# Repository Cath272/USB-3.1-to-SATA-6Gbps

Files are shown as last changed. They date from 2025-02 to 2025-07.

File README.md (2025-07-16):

# USB-3.1-to-SATA-6Gbps
USB 3.2 gen 2 (SuperSpeed+ 10Gbps) to SATA 6Gbps

This Board is based on the VIA Labs VL716 

## VL716

- High performance, low power single chip USB 3.1 to SATA 6Gb/s bridge controller 
- USB Type-C connector support
###  Built-in Voltage Regulators

- 5.0V to 3.3V LDO

- 5.0V to 1.2V switching DC-DC

## Other Parts 

- USB C 24P Connector (THT inside pins)
- 25Mhz Crystal for Ic
- Sata 22P horizontal female SMD connector
- W25Q16BVSSIG 16Mbit SPI Flash  Memory
- 1.5uH/2.2uH Inductor
- Power/Busy LEDs

## PCB 
This board uses a 4 layer stackup with a  1.6mm thickness:

- POWER/SIGNAL

- GND
  
- GND
  
- POWER/SIGNAL

High Speed diferential lines need a refrence ground plane so internal planes are ground referance planes for the High speed USB lines

The Pcb was inspired by similar boards that use VL711/VL715 Ics. The capacitors are standard values that are use as decoupling capacitors.

### Schematic:
Schematic

## PCB Screenshots

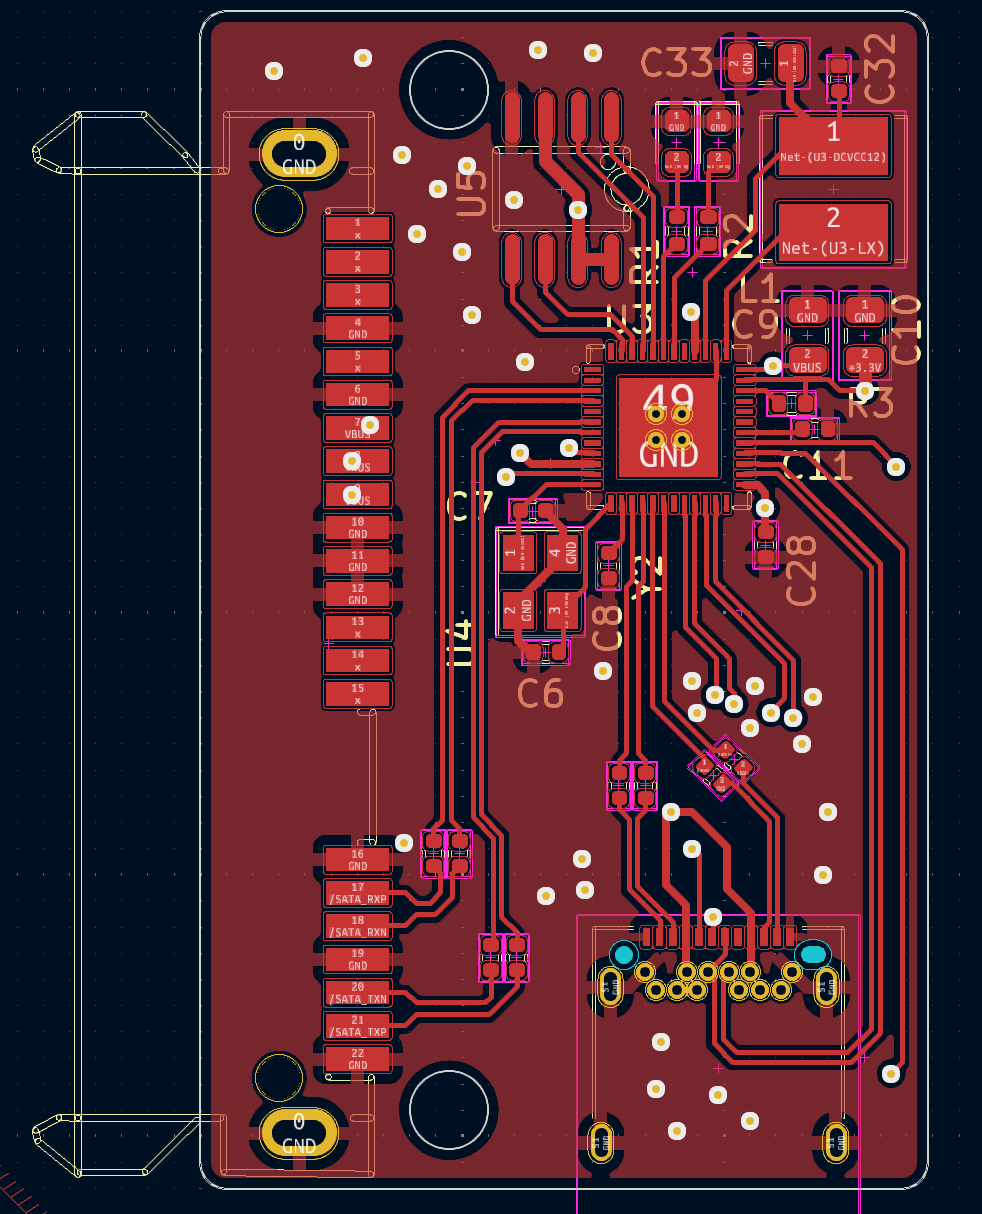
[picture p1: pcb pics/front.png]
usb3satafront

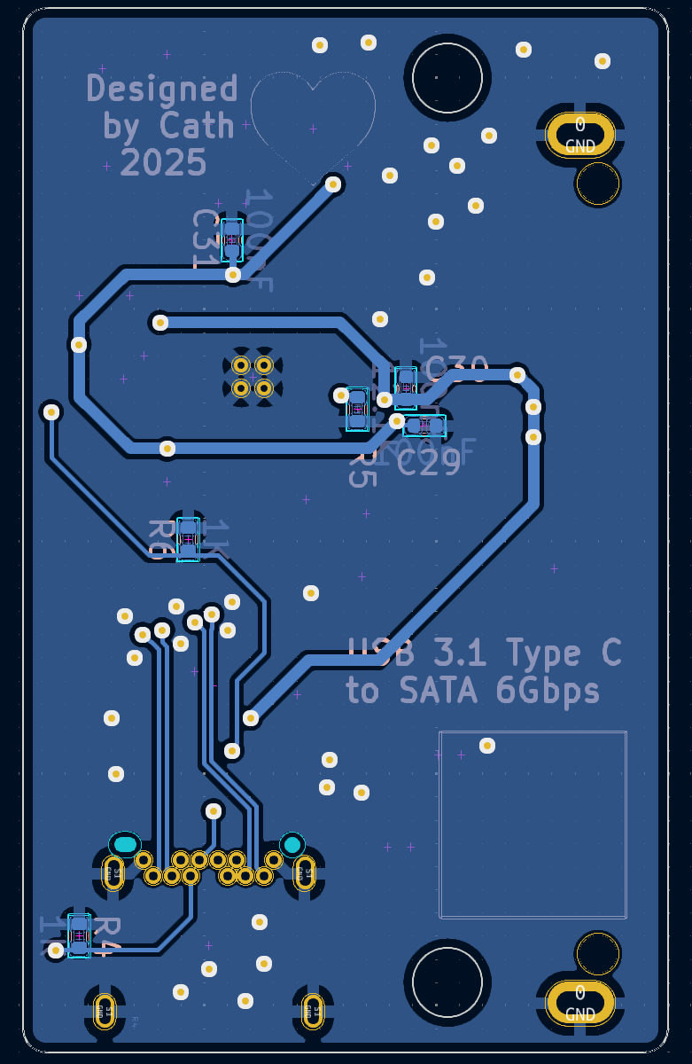
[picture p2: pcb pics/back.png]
usb3sataback

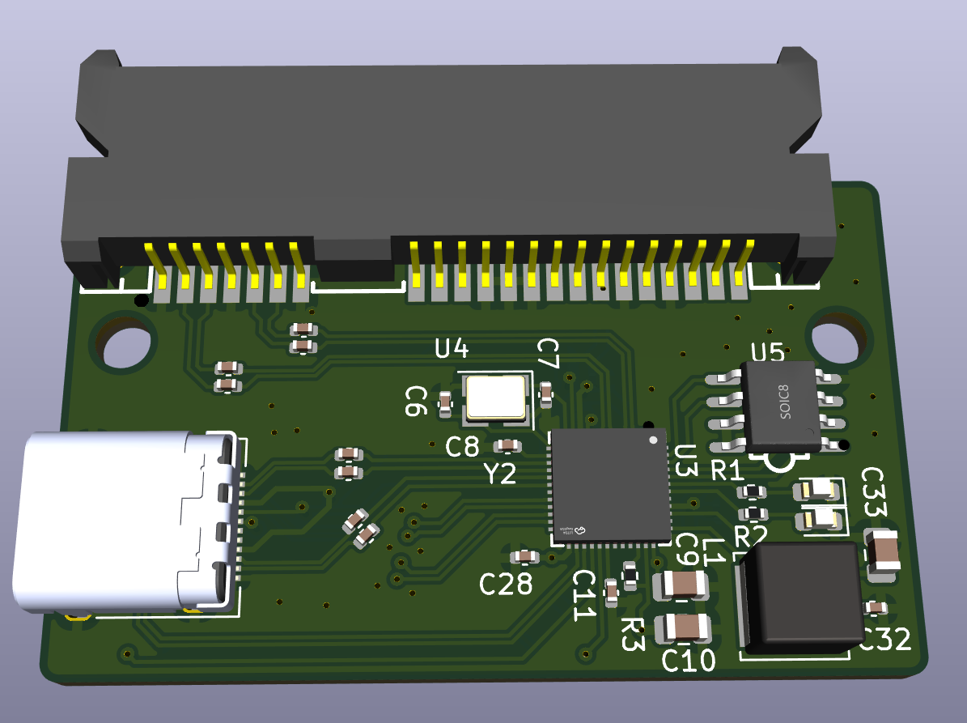
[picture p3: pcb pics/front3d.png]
usb3satafront3d

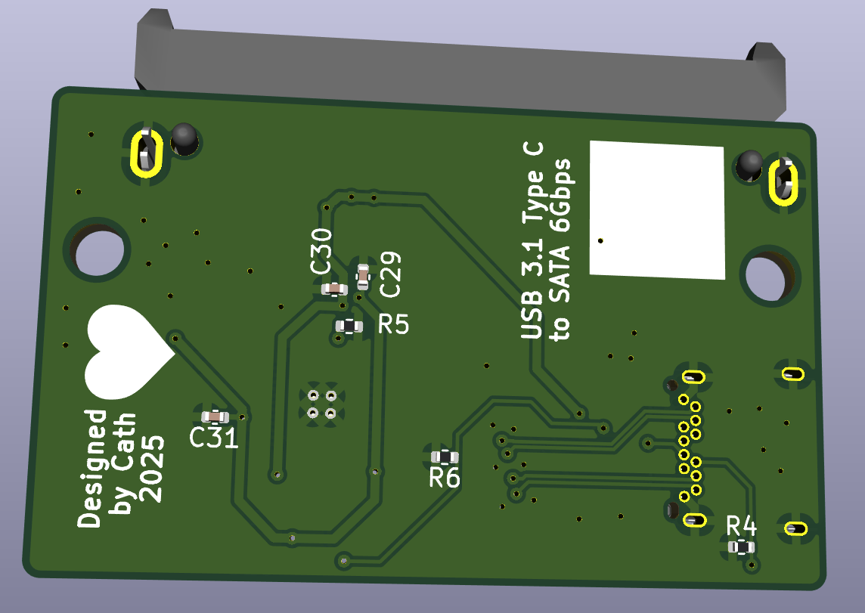
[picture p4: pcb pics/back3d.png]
usb3sataback3d


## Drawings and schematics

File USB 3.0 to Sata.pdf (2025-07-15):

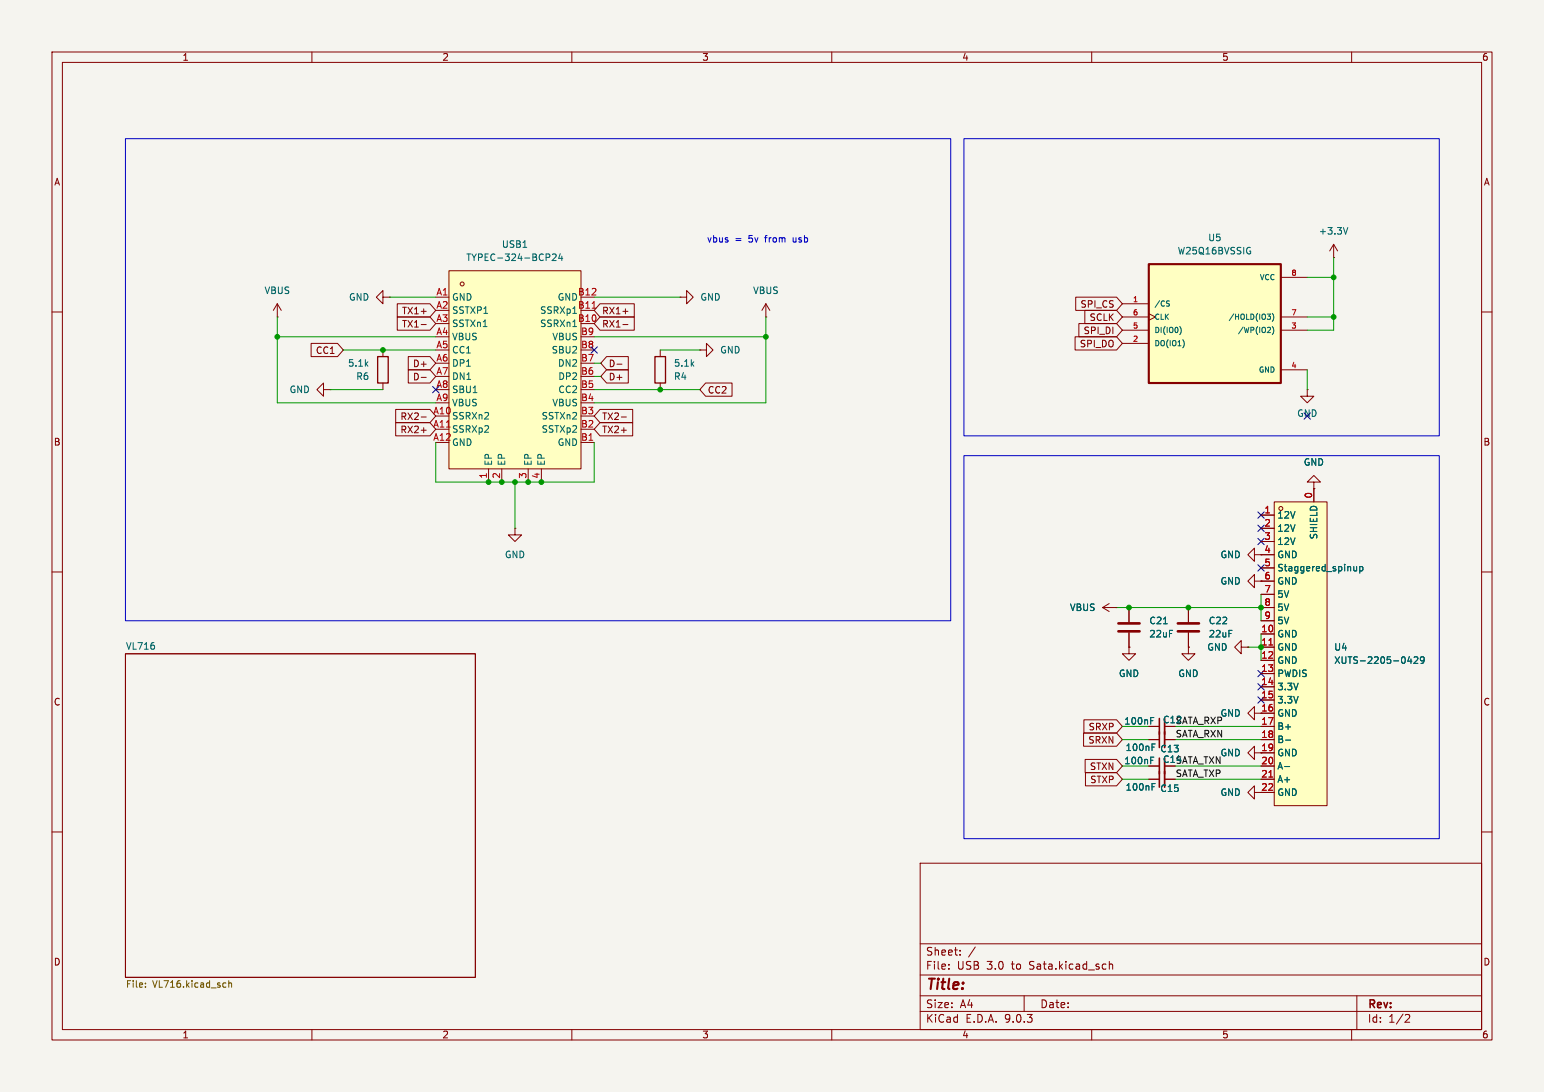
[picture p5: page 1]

4 GNDB12 SSRXp1 B11 SSRXn1 B10 VBUS B9 SBU2 B8 DN2 B7 DP2 B6 CC2 B5 VBUS B4 SSTXn2 B3 SSTXp2 B2 GND B1 USB1 TYPEC-324-BCP24

Id: 1/2 Title: File: USB 3.0 to Sata.kicad_sch Sheet: / VL716 File: VL716.kicad_sch

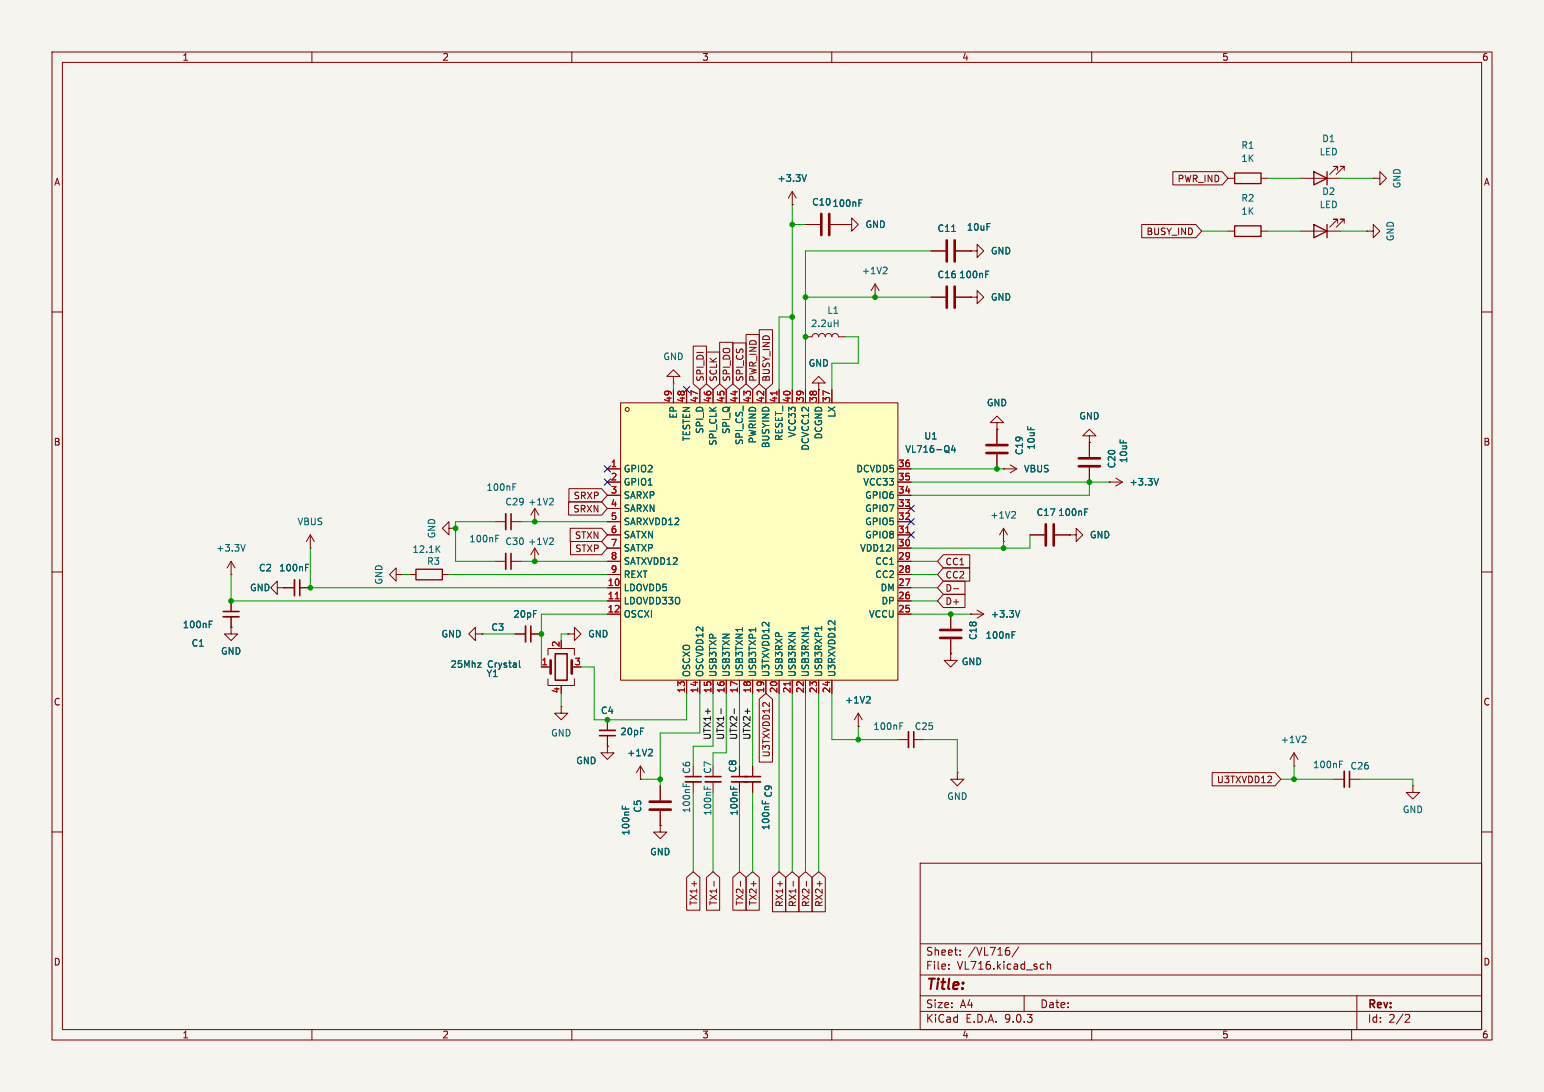
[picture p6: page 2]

Id: 2/2 Title: File: VL716.kicad_sch Sheet: /VL716/

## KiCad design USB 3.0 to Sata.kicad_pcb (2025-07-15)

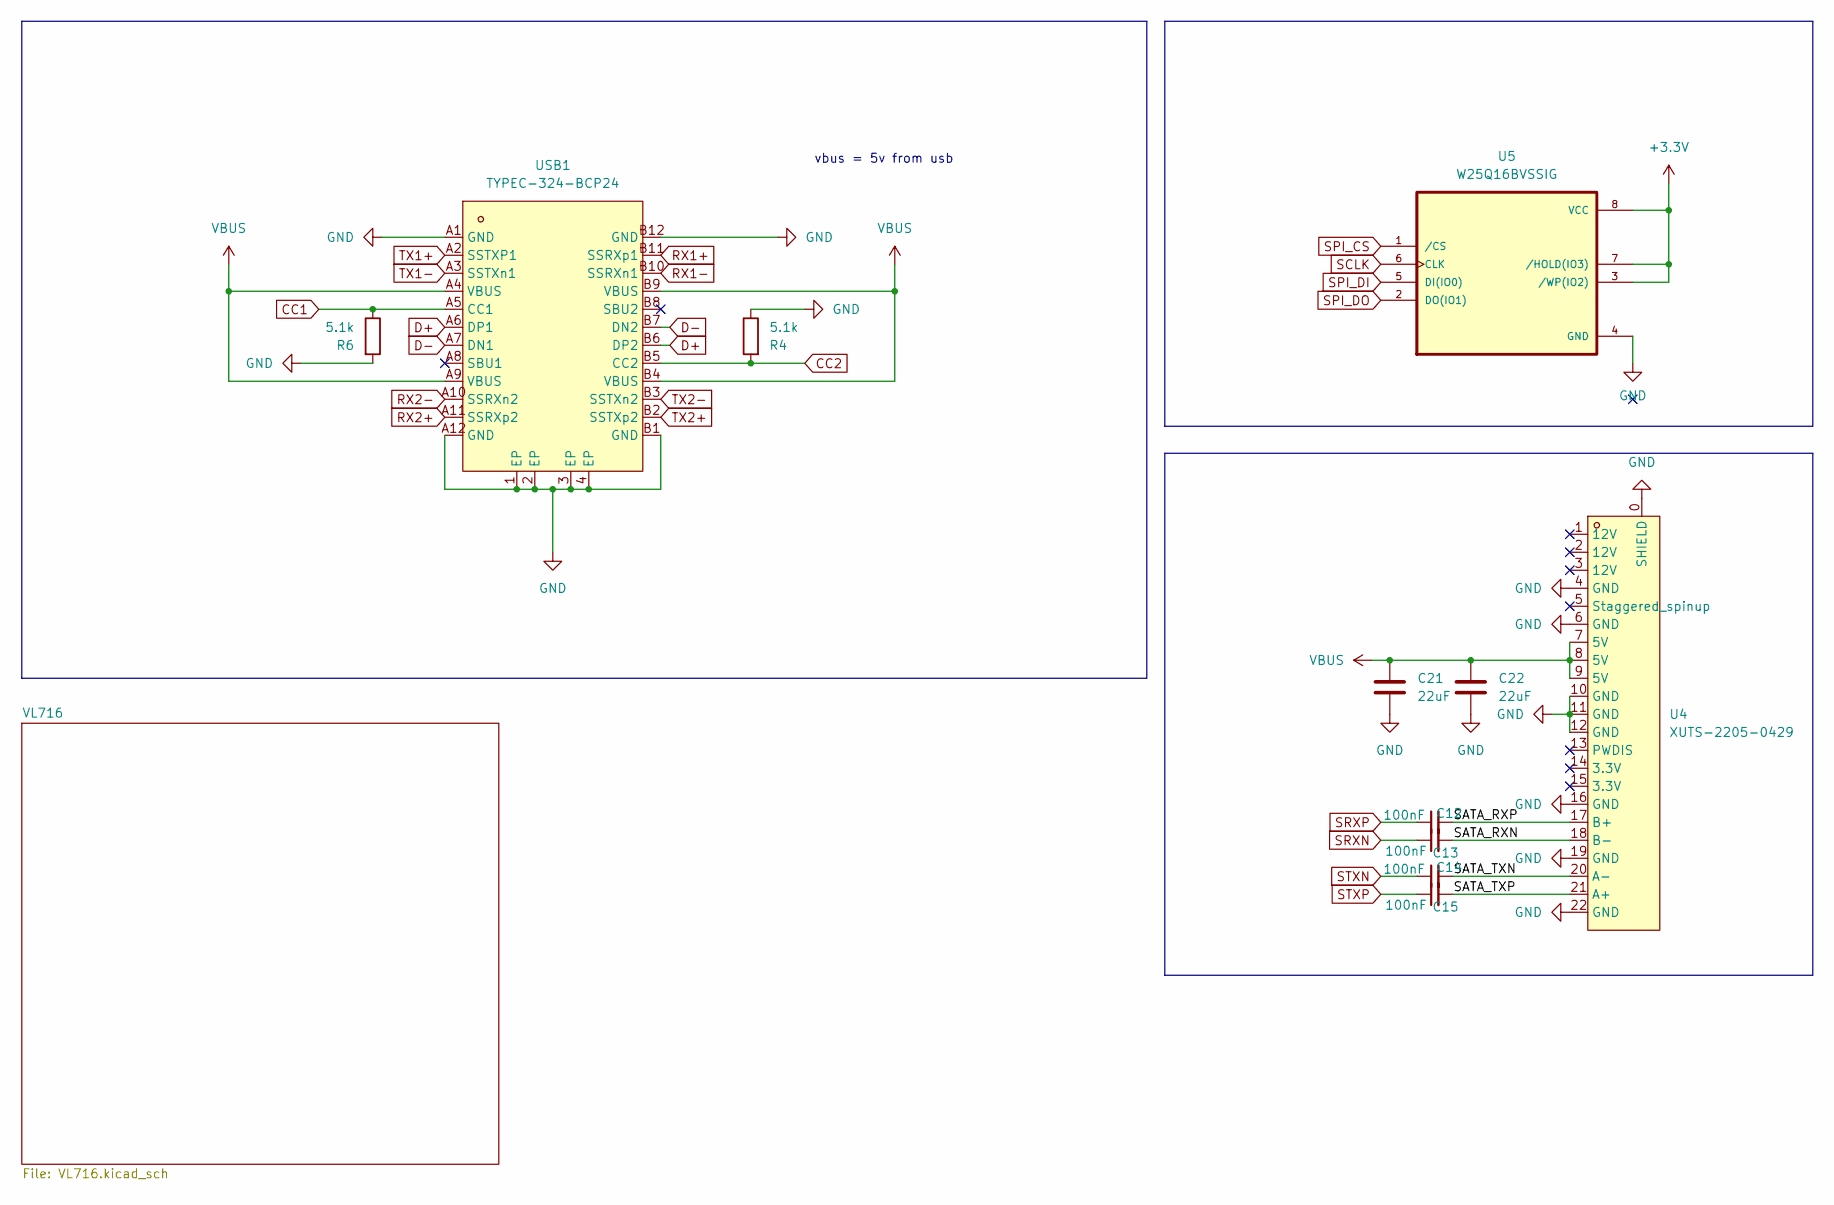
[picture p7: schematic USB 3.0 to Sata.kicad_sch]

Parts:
C12, C13, C14, C15: 100nF; C_0402_1005Metric
C21, C22: 22uF; C_0805_2012Metric
R4, R6: 5.1k; R_0402_1005Metric
U4: XUTS-2205-0429; CONN-SMD_UTS-2205-0429; LCSC Part C7527511
U5: W25Q16BVSSIG; SOIC-8_L5.3-W5.3-P1.27-LS8.0-BL; PARTREV F
USB1: TYPEC-324-BCP24; USB-C-SMD_TYPEC-324-BCP24; LCSC Part C2835314

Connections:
+3.3V: U5.3 (/WP(IO2)), U5.7 (/HOLD(IO3)), U5.8 (VCC); also elsewhere on the board
/SATA_RXN: C13.2, U4.18 (B-)
/SATA_RXP: C12.2, U4.17 (B+)
/SATA_TXN: C14.2, U4.20 (A-)
/SATA_TXP: C15.2, U4.21 (A+)
CC1: R6.1, USB1.A5 (CC1); also elsewhere on the board
CC2: R4.2, USB1.B5 (CC2); also elsewhere on the board
D+: USB1.A6 (DP1), USB1.B6 (DP2); also elsewhere on the board
D-: USB1.A7 (DN1), USB1.B7 (DN2); also elsewhere on the board
GND: C21.2, C22.2, R4.1, R6.2, U4.0 (SHIELD), U4.4 (GND), U4.6 (GND), U4.10 (GND), U4.11 (GND), U4.12 (GND), U4.16 (GND), U4.19 (GND), U4.22 (GND), U5.4 (GND), USB1.1 (EP), USB1.2 (EP), USB1.3 (EP), USB1.4 (EP), USB1.A1 (GND), USB1.A12 (GND), USB1.B1 (GND), USB1.B12 (GND); also elsewhere on the board
RX1+: USB1.B11 (SSRXp1); also elsewhere on the board
RX1-: USB1.B10 (SSRXn1); also elsewhere on the board
RX2+: USB1.A11 (SSRXp2); also elsewhere on the board
RX2-: USB1.A10 (SSRXn2); also elsewhere on the board
SCLK: U5.6 (CLK); also elsewhere on the board
SPI_CS: U5.1 (/CS); also elsewhere on the board
SPI_DI: U5.5 (DI(IO0)); also elsewhere on the board
SPI_DO: U5.2 (DO(IO1)); also elsewhere on the board
SRXN: C13.1; also elsewhere on the board
SRXP: C12.1; also elsewhere on the board
STXN: C14.1; also elsewhere on the board
STXP: C15.1; also elsewhere on the board
TX1+: USB1.A2 (SSTXP1); also elsewhere on the board
TX1-: USB1.A3 (SSTXn1); also elsewhere on the board
TX2+: USB1.B2 (SSTXp2); also elsewhere on the board
TX2-: USB1.B3 (SSTXn2); also elsewhere on the board
VBUS: C21.1, C22.1, U4.7 (5V), U4.8 (5V), U4.9 (5V), USB1.A4 (VBUS), USB1.A9 (VBUS), USB1.B4 (VBUS), USB1.B9 (VBUS); also elsewhere on the board

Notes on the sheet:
vbus = 5v from usb

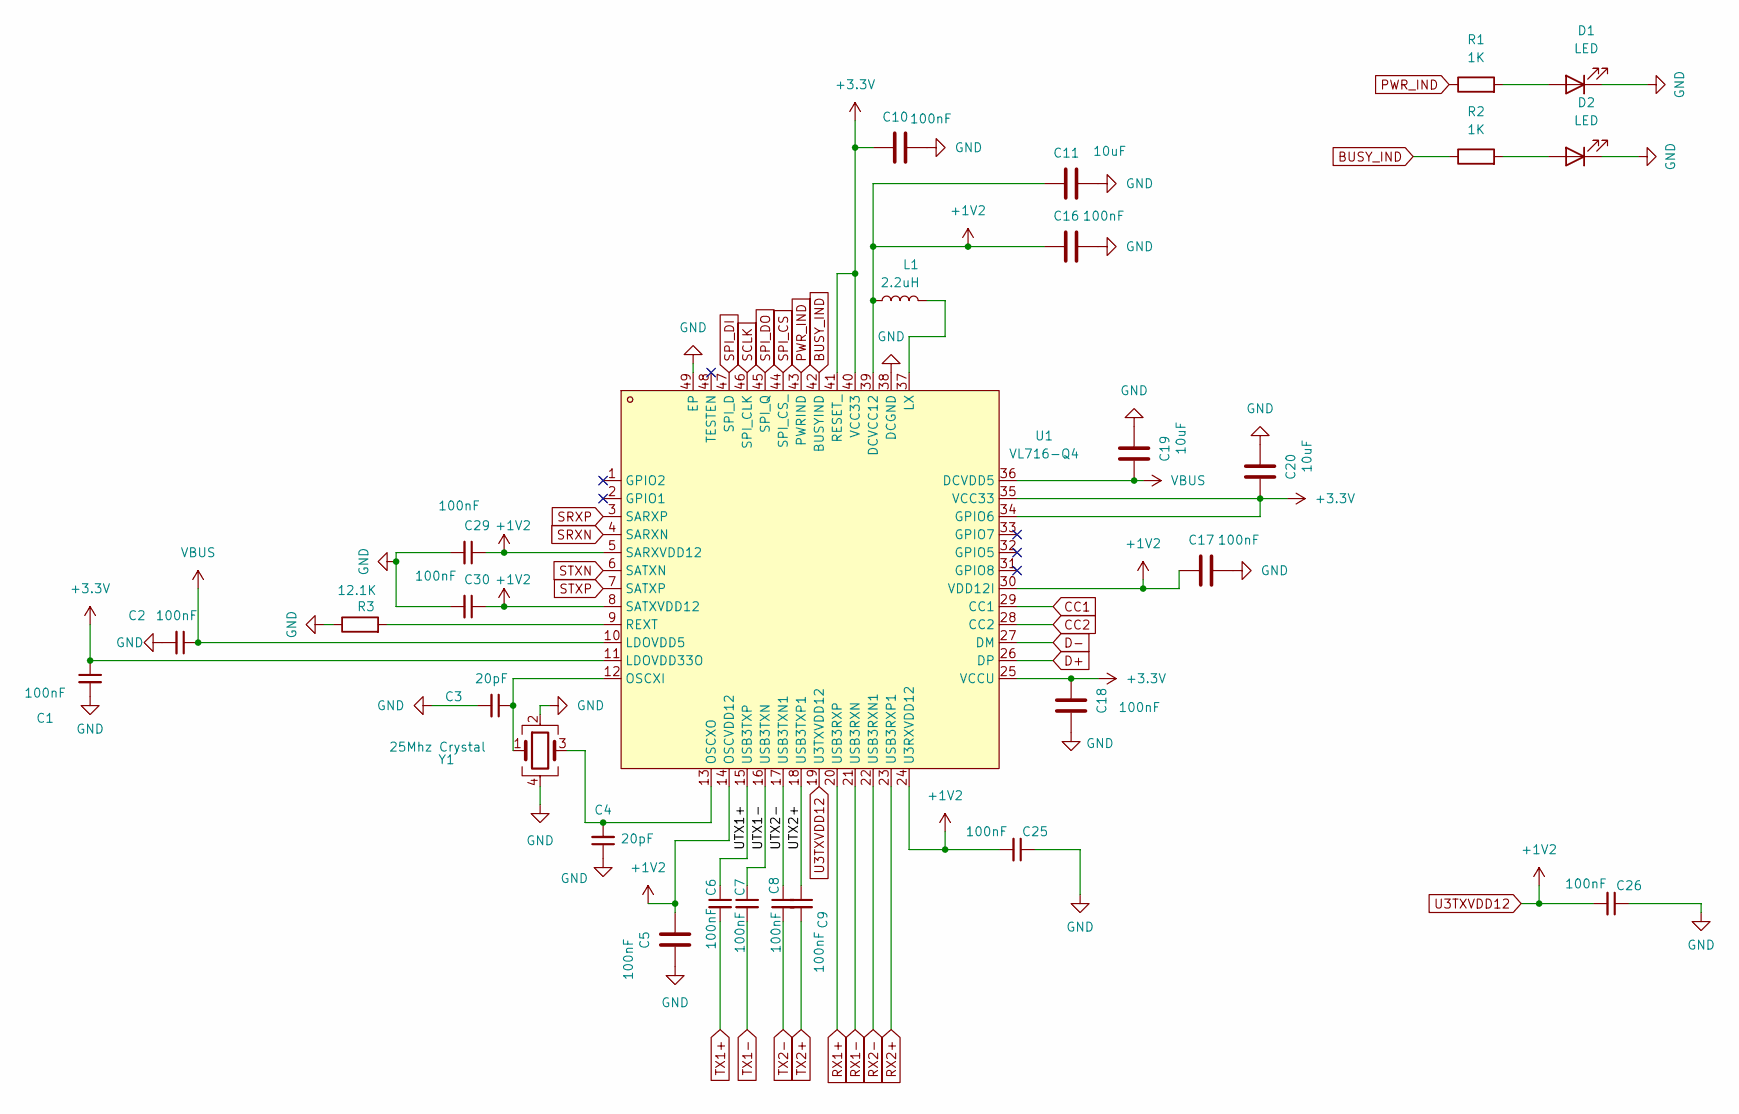
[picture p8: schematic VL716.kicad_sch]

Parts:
C1, C2, C5, C6, C7, C8, C9, C10, C16, C17, C18, C25, C26, C29, C30: 100nF; C_0402_1005Metric
C3, C4: 20pF; C_0402_1005Metric
C11, C19, C20: 10uF; C_0805_2012Metric
D1, D2: LED; LED_0603_1608Metric
L1: 2.2uH; L_Cenker_CKCS4030
R1, R2: 1K; R_0402_1005Metric
R3: 12.1K; R_0402_1005Metric
U1: VL716-Q4; QFN-48_L6.0-W6.0-P0.40-BL-EP3.8; LCSC Part C69727
Y1: 25Mhz Crystal; Crystal_SMD_3225-4Pin_3.2x2.5mm

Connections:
+3.3V: C1.1, C10.1, C18.1, C20.2, U1.11 (LDOVDD33O), U1.25 (VCCU), U1.34 (GPIO6), U1.35 (VCC33), U1.40 (VCC33), U1.41 (RESET_); also elsewhere on the board
/VL716/UTX1+: C6.1, U1.15 (USB3TXP)
/VL716/UTX1-: C7.1, U1.16 (USB3TXN)
/VL716/UTX2+: C9.1, U1.18 (USB3TXP1)
/VL716/UTX2-: C8.1, U1.17 (USB3TXN1)
BUSY_IND: R2.1, U1.42 (BUSYIND)
CC1: U1.29 (CC1); also elsewhere on the board
CC2: U1.28 (CC2); also elsewhere on the board
D+: U1.26 (DP); also elsewhere on the board
D-: U1.27 (DM); also elsewhere on the board
GND: C1.2, C2.2, C3.2, C4.1, C5.1, C10.2, C11.2, C16.2, C17.2, C18.2, C19.1, C20.1, C25.1, C26.1, C29.2, C30.2, D1.1 (K), D2.1 (K), R3.1, U1.38 (DCGND), U1.49 (EP), Y1.2, Y1.4; also elsewhere on the board
unnamed: D1.2 (A), R1.2
unnamed: D2.2 (A), R2.2
unnamed: L1.2, U1.37 (LX)
unnamed: C3.1, U1.12 (OSCXI), Y1.1
unnamed: C4.2, U1.13 (OSCXO), Y1.3
unnamed: R3.2, U1.9 (REXT)
PWR_IND: R1.1, U1.43 (PWRIND)
RX1+: U1.20 (USB3RXP); also elsewhere on the board
RX1-: U1.21 (USB3RXN); also elsewhere on the board
RX2+: U1.23 (USB3RXP1); also elsewhere on the board
RX2-: U1.22 (USB3RXN1); also elsewhere on the board
SCLK: U1.46 (SPI_CLK); also elsewhere on the board
SPI_CS: U1.44 (SPI_CS_); also elsewhere on the board
SPI_DI: U1.47 (SPI_D); also elsewhere on the board
SPI_DO: U1.45 (SPI_Q); also elsewhere on the board
SRXN: U1.4 (SARXN); also elsewhere on the board
SRXP: U1.3 (SARXP); also elsewhere on the board
STXN: U1.6 (SATXN); also elsewhere on the board
STXP: U1.7 (SATXP); also elsewhere on the board
TX1+: C6.2; also elsewhere on the board
TX1-: C7.2; also elsewhere on the board
TX2+: C9.2; also elsewhere on the board
TX2-: C8.2; also elsewhere on the board
U3TXVDD12: C5.2, C11.1, C16.1, C17.1, C25.2, C26.2, C29.1, C30.1, L1.1, U1.5 (SARXVDD12), U1.8 (SATXVDD12), U1.14 (OSCVDD12), U1.19 (U3TXVDD12), U1.24 (U3RXVDD12), U1.30 (VDD12I), U1.39 (DCVCC12)
VBUS: C2.1, C19.2, U1.10 (LDOVDD5), U1.36 (DCVDD5); also elsewhere on the board

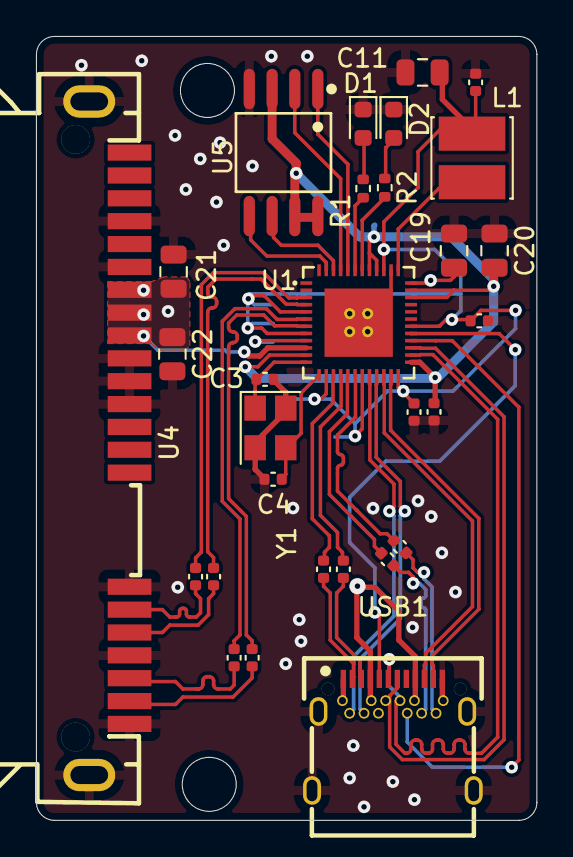
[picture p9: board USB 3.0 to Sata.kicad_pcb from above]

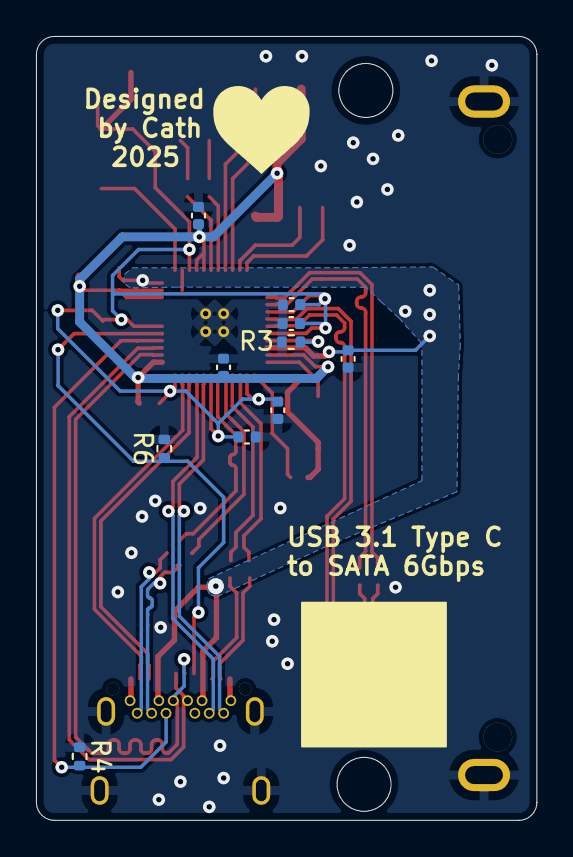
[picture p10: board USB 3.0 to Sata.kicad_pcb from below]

Board: 4 copper layers, 27.8 x 43.5 mm, 39 parts (10 on the bottom side), 40 nets.

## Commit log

2025-02-05 Updated Schematic and Uploaded PCB files
    [USB 3.0 to Sata.kicad_pcb, USB 3.0 to Sata.kicad_sch]
2025-02-05 Updated PCB Pictures
2025-02-21 Fixed pcb errors
    Fixed RX2 TX2 lines being flipped, changed usb port footprint to the corect one, changed flash footprint from SOP8-150MIL to SOP8-208MIL
    [USB 3.0 to Sata.kicad_pcb, USB 3.0 to Sata.kicad_sch, VL716.kicad_sch]
2025-03-05 Fixed layout
    Fixed traces length
    [USB 3.0 to Sata.kicad_pcb, VL716.kicad_sch]
